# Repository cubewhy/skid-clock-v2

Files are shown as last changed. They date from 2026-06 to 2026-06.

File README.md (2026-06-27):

# Skid Clock v2

> [!IMPORTANT]
>
> 我们假设您拥有3D 打印机或者可以生产外壳。
>
> 如果没有可以用纸盒代替

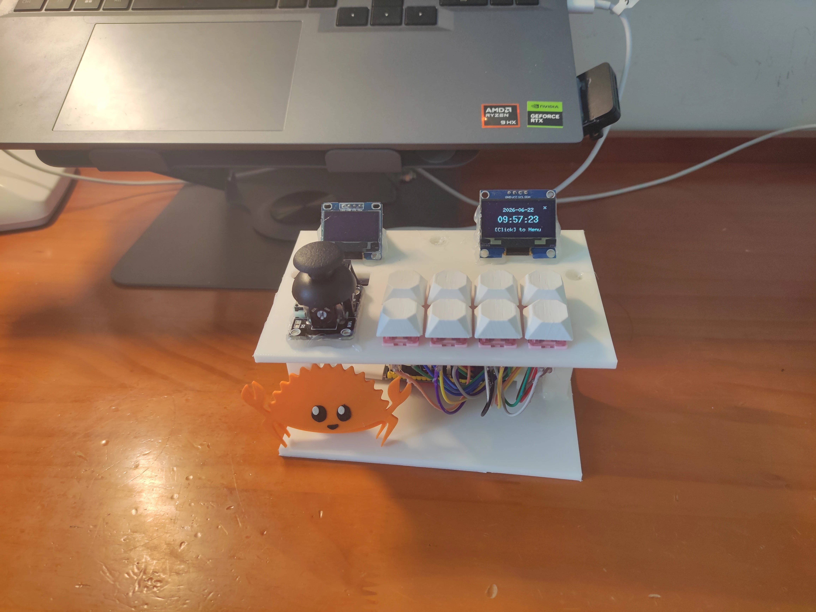
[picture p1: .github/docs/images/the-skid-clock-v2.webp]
the-skid-clock


还在为水课发愁吗? 试试这款桌面时钟, 有一个 ESP32-S3 就可以制作, 轻松跳过水课!

## 功能矩阵

- 时钟
- 停表
- 倒计时
- 番茄钟
- 计算器
- Wi-Fi 连接支持 (支持记忆密码)
- NTP 同步支持
- 小游戏

### 小游戏列表

- 贪吃蛇
- 俄罗斯方块
- 乒乓球
- 谷歌小恐龙
- 堆叠叠罗汉
- 见缝插针
- 打靶
- 跳一跳
- 打地鼠
- 简易版战舰棋
- 坦克动荡
- 2048
- Flappy Bird
- 黄金矿工
- 五子棋
- 打砖块
- 传说之下 (丐版)
- 吃豆人

## 自己组装

### 原材料/工具

| 名称 | 数量 |
| --- | --- |
| ESP32s3 | 1 |
| 机械键盘轴 | 8 |
| 二极管 | 8 |
| 摇杆 | 1 |
| Sh1106 1.3″ 屏幕 | 1 |
| Ssd1306 0.96″ 屏幕 | 1 |
| DS1306 时钟模块 | 1 |
| 面包板 | 1 |
| 杜邦线 | ~45 根 |
| 3D打印机 | 1 (可选) |
| 热熔胶 | 1 |
| 电烙铁 | 1 |
| 镊子 | 1 |

### 制作外壳 (3D打印)

> 如果你要3D 打印键帽: [Printables](https://www.printables.com/model/399607-complete-cherry-mx-stem-keycap-set-optimized-for-3)

- 下载 FreeCAD
- 下载 [工程文件](./models/skid-clock.FCStd) [Printables](https://www.printables.com/model/1765657-skid-clock)
- 导出为 `.3mf` 或者 `.step`
- 用切片软件导出 GCode
- 发送到打印机, 打印!

### 制作外壳 (纸盒子)

- 在顶部开8个 14x14mm 口, 用于放机械键盘按键
- 放入机械键盘按键, 粘贴屏幕和摇杆即可

### 组装

> [!IMPORTANT]
> 先连接电路再粘贴顶板和底板!

- 放置两块屏幕, 用热熔胶粘到外壳的斜坡上
- 将8个轴卡到对应的卡槽中 (不需要热熔胶固定)
- 将杜邦线接到键盘轴上, 并用热熔胶固定 (需要拨开外壳, 使用镊子即可)
- 粘贴摇杆 (没有开槽, 多打一点热熔胶)
- 在顶盖背面粘贴 DS1306 时钟模块
- 将所有线连到 ESP32s3 上 ([引脚信息](#引脚信息))
- 将 ESP32s3 划入底板的卡槽中
- 确认接线无误, 用热熔胶粘贴底板上的三个柱子和顶盖

### 引脚信息

> 你可以在这里找到引脚定义代码 [main.rs](https://github.com/cubewhy/skid-clock-v2/blob/master/src/main.rs)

| GPIO | 说明 |
| ---- | --- |
| 4 | 键盘 row1 |
| 5 | 键盘 row2 |
| 6 | 键盘 col1 |
| 16 | 键盘 col2 |
| 15 | 键盘 col3 |
| 13 | 键盘 col4 |
| 9 | I2C SDA |
| 8 | I2C SCL |
| 10 | DS1306 CLK |
| 11 | DS1306 DAT |
| 12 | DS1306 RST |
| 3 | 摇杆 VRX (X 轴) |
| 7 | 摇杆 VRY (Y 轴) |
| 18 | 摇杆中键 |

#### 搭建矩阵扫描电路

#### I2C 地址

> 你需要使用电烙铁焊接屏幕背后的焊点来切换地址

| 地址 | 说明 |
| ---- | --- |
| 0x3D | 1.3″ OLED 屏幕  |
| 0x3C | 0.96″ OLED 屏幕 |

## License

Licensed under GPL-3.0

You're allowed to use, share and modify

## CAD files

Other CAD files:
models/skid-clock.FCStd

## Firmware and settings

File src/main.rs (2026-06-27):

use std::{
    cell::RefCell,
    sync::{Arc, Mutex},
    thread,
    time::{Duration, Instant},
};

use crate::{
    app_context::{AppContext, UpdateContext},
    apps::App,
    display::{Sh1106Unified, Ssd1306Unified, UnifiedDisplay},
    input::{InputManager, JoystickRotation},
    network_manager::NetworkController,
    pin_config::{
        I2cDisplayPinConfig, JoyPinConfig, KeyboardMatrixConfig, PinConfig, RtcPinConfig,
    },
    rtc::{ds1302::Ds1302, init_timezone, sync_rtc_to_system},
    ui::UiEvents,
};
use embedded_graphics::{draw_target::DrawTarget, pixelcolor::BinaryColor};
use embedded_hal_bus::i2c::RefCellDevice;
use esp_idf_svc::{
    eventloop::EspSystemEventLoop,
    hal::{
        gpio::PinDriver,
        i2c::{I2cConfig, I2cDriver},
        peripherals::Peripherals,
        units::MegaHertz,
    },
    nvs::EspDefaultNvsPartition,
};
use mini_oled::screen::sh1106::Sh1106;
use ssd1306::{I2CDisplayInterface, Ssd1306, mode::DisplayConfig, size::DisplaySize128x64};
use u8g2_fonts::{FontRenderer, fonts};

pub mod app_context;
pub mod apps;
pub mod display;
pub mod input;
pub mod network_manager;
pub mod pin_config;
pub mod rtc;
pub mod secret_manager;
pub mod ui;

fn main() -> anyhow::Result<()> {
    // It is necessary to call this function once. Otherwise, some patches to the runtime
    // implemented by esp-idf-sys might not link properly. See https://github.com/esp-rs/esp-idf-template/issues/71
    esp_idf_svc::sys::link_patches();

    // Bind the log crate to the ESP Logging facilities
    esp_idf_svc::log::EspLogger::initialize_default();

    let peripherals = Peripherals::take().unwrap();
    let sys_loop = EspSystemEventLoop::take()?;
    let nvs = EspDefaultNvsPartition::take()?;
    let pins = peripherals.pins;

    let network_controller = NetworkController::new(peripherals.modem, sys_loop, nvs)?;

    // NOTE: Change the GPIO config if you connected the hardware in different ports
    let pin_config = PinConfig {
        keyboard: KeyboardMatrixConfig {
            rows: [pins.gpio4.degrade_output(), pins.gpio5.degrade_output()],
            cols: [
                pins.gpio6.degrade_input(),
                pins.gpio16.degrade_input(),
                pins.gpio15.degrade_input(),
                pins.gpio13.degrade_input(),
            ],
        },
        i2c_display: I2cDisplayPinConfig {
            sda: pins.gpio9.degrade_input_output(),
            scl: pins.gpio8.degrade_input_output(),
            addr_1_3_in: 0x3D,
            addr_0_96_in: 0x3C,
        },
        rtc: RtcPinConfig {
            clk: pins.gpio10.degrade_output(),
            dat: pins.gpio11.degrade_input_output(),
            rst: pins.gpio12.degrade_output(),
        },
        joy: JoyPinConfig {
            x: pins.gpio3.degrade_input(),
            y: pins.gpio7.degrade_input(),
            sw: pins.gpio18.degrade_input(),
        },
    };

    let mut rtc_driver = {
        let pins = pin_config.rtc;
        let clk_pin = PinDriver::output(pins.clk)?;
        let dat_pin = PinDriver::input_output(pins.dat, esp_idf_svc::hal::gpio::Pull::Floating)?;
        let rst_pin = PinDriver::output(pins.rst)?;

        Ds1302::new(clk_pin, dat_pin, rst_pin)
    };
    rtc_driver.init()?;

    sync_rtc_to_system(&mut rtc_driver)?;

    let mut input_manager = InputManager::build(
        pin_config.keyboard,
        pin_config.joy,
        JoystickRotation::Deg270,
    )?;

    let i2c_cfg = I2cConfig::new().baudrate(MegaHertz::from(1).into());
    let i2c_driver = I2cDriver::new(
        peripherals.i2c0,
        pin_config.i2c_display.sda,
        pin_config.i2c_display.scl,
        &i2c_cfg,
    )?;

    let i2c_bus_shared = RefCell::new(i2c_driver);
    let i2c_dev_for_ssd = RefCellDevice::new(&i2c_bus_shared);
    let i2c_dev_for_sh = RefCellDevice::new(&i2c_bus_shared);

    let ssd_interface = I2CDisplayInterface::new_custom_address(
        i2c_dev_for_ssd,
        pin_config.i2c_display.addr_0_96_in,
    );
    let mut display_0_96 = Ssd1306::new(
        ssd_interface,
        DisplaySize128x64,
        ssd1306::prelude::DisplayRotation::Rotate0,
    )
    .into_buffered_graphics_mode();
    display_0_96
        .init()
        .map_err(|e| anyhow::anyhow!("{:?}", e))?;

    let sh_interface =
        mini_oled::prelude::I2cInterface::new(i2c_dev_for_sh, pin_config.i2c_display.addr_1_3_in);
    let mut display_1_3 = Sh1106::new(sh_interface);
    display_1_3.init().map_err(|e| anyhow::anyhow!("{:?}", e))?;

    let font = FontRenderer::new::<fonts::u8g2_font_6x10_tr>();
    let font_large = FontRenderer::new::<fonts::u8g2_font_10x20_tr>();

    let start_time = Instant::now();

    let mut last_tick = Instant::now();
    let target_frame_time = Duration::from_millis(20); // 50fps

    let mut active_app = App::Clock;

    let shared_events = Arc::new(Mutex::new(Vec::<UiEvents>::new()));

    init_timezone();

    loop {
        input_manager.scan().unwrap();

        let menu_events = input_manager.get_menu_events();

        if !menu_events.is_empty()
            && let Ok(mut events) = shared_events.lock()
        {
            events.push(menu_events);
        }

        let now = Instant::now();
        let elapsed = now.duration_since(last_tick);

        if elapsed >= target_frame_time {
            let frame_events = {
                if let Ok(mut events_guard) = shared_events.lock() {
                    std::mem::take(&mut *events_guard)
                } else {
                    Vec::new()
                }
            };

            if frame_events.is_empty() {
                let mut update_ctx = UpdateContext {
                    menu_events: UiEvents::empty(),
                    rtc: &mut rtc_driver,
                    input_manager: &input_manager,
                    uptime_secs: start_time.elapsed().as_secs(),
                    network: &network_controller,
                };
                if let Some(new_app) = active_app.update(&mut update_ctx) {
                    active_app = new_app;
                }
            } else {
                for events in frame_events {
                    let mut update_ctx = UpdateContext {
                        menu_events: events,
                        rtc: &mut rtc_driver,
                        input_manager: &input_manager,
                        uptime_secs: start_time.elapsed().as_secs(),
                        network: &network_controller,
                    };
                    if let Some(new_app) = active_app.update(&mut update_ctx) {
                        active_app = new_app;
                    }
                }
            }

            let mut app_ctx = AppContext {
                display_0_96: Ssd1306Unified::new(&mut display_0_96),
                display_1_3: Sh1106Unified::new(&mut display_1_3),
                font: &font,
                font_large: &font_large,
                uptime_secs: start_time.elapsed().as_secs(),
                input: &input_manager,
                network: &network_controller,
            };

            app_ctx.display_0_96.clear(BinaryColor::Off).ok();
            app_ctx.display_1_3.clear(BinaryColor::Off).ok();

            active_app.draw(&mut app_ctx)?;

            app_ctx.display_0_96.flush().ok();
            app_ctx.display_1_3.flush().ok();

            last_tick = Instant::now();
        }

        thread::yield_now();
    }
}

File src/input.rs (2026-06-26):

use crate::ui::ctx::UiEvents;
use esp_idf_svc::hal::gpio::{AnyInputPin, Input, Output, PinDriver, Pull};
use std::time::Instant;

const ALL_EVENTS: &[UiEvents] = &[
    UiEvents::UP,
    UiEvents::DOWN,
    UiEvents::LEFT,
    UiEvents::RIGHT,
    UiEvents::CONFIRM,
    UiEvents::KEY_ESC,
    UiEvents::KEY_1,
    UiEvents::KEY_2,
    UiEvents::KEY_3,
    UiEvents::KEY_4,
    UiEvents::KEY_5,
    UiEvents::KEY_6,
    UiEvents::KEY_7,
];

#[derive(Debug, Clone, Copy, PartialEq, Eq)]
pub enum JoystickRotation {
    Deg0,
    Deg90,
    Deg180,
    Deg270,
}

#[derive(Debug, Clone, Copy, Default)]
pub struct JoystickData {
    pub x: f32,
    pub y: f32,
    pub is_pressed: bool,
}

impl JoystickData {
    /// Evaluates stick vectors into UiEvents using hysteresis to prevent border jittering.
    pub fn get_events(&self, prev_events: UiEvents) -> UiEvents {
        let mut events = UiEvents::empty();

        // Hysteresis thresholds to eliminate analog signal noise around boundaries
        let press_thresh: f32 = 0.6;
        let release_thresh: f32 = 0.4;

        // Y-Axis evaluation (UP / DOWN)
        if prev_events.contains(UiEvents::UP) {
            if self.y > release_thresh {
                events.insert(UiEvents::UP);
            }
        } else {
            if self.y > press_thresh {
                events.insert(UiEvents::UP);
            }
        }

        if prev_events.contains(UiEvents::DOWN) {
            if self.y < -release_thresh {
                events.insert(UiEvents::DOWN);
            }
        } else {
            if self.y < -press_thresh {
                events.insert(UiEvents::DOWN);
            }
        }

        // X-Axis evaluation (LEFT / RIGHT) - preserving original mapped polarity
        if prev_events.contains(UiEvents::RIGHT) {
            if self.x < -release_thresh {
                events.insert(UiEvents::RIGHT);
            }
        } else {
            if self.x < -press_thresh {
                events.insert(UiEvents::RIGHT);
            }
        }

        if prev_events.contains(UiEvents::LEFT) {
            if self.x > release_thresh {
                events.insert(UiEvents::LEFT);
            }
        } else {
            if self.x > press_thresh {
                events.insert(UiEvents::LEFT);
            }
        }

        if self.is_pressed {
            events.insert(UiEvents::CONFIRM);
        }

        events
    }
}

#[derive(Debug, Clone, Copy, Default)]
pub struct KeyStates {
    pub esc: bool,
    pub btn_1: bool,
    pub btn_2: bool,
    pub btn_3: bool,
    pub btn_4: bool,
    pub btn_5: bool,
    pub btn_6: bool,
    pub btn_7: bool,
}

impl KeyStates {
    pub fn get_events(&self) -> UiEvents {
        let mut events = UiEvents::empty();

        if self.esc {
            events.insert(UiEvents::KEY_ESC);
        }
        if self.btn_1 {
            events.insert(UiEvents::KEY_1);
        }
        if self.btn_2 {
            events.insert(UiEvents::KEY_2);
        }
        if self.btn_3 {
            events.insert(UiEvents::KEY_3);
        }
        if self.btn_4 {
            events.insert(UiEvents::KEY_4);
        }
        if self.btn_5 {
            events.insert(UiEvents::KEY_5);
        }
        if self.btn_6 {
            events.insert(UiEvents::KEY_6);
        }
        if self.btn_7 {
            events.insert(UiEvents::KEY_7);
        }

        events
    }
}

pub struct InputManager<'a> {
    pub rows: [PinDriver<'a, Output>; 2],
    pub cols: [PinDriver<'a, Input>; 4],

    pub btn_joy_sw: PinDriver<'a, Input>,

    pub joy_x_pin: AnyInputPin<'a>,
    pub joy_y_pin: AnyInputPin<'a>,
    pub joy_rotation: JoystickRotation,

    pub key_states: KeyStates,

    current_events: UiEvents,
    previous_events: UiEvents,
    menu_events: UiEvents,
    released_events: UiEvents,

    last_scan_time: Instant,
    debounce_ms: [u32; 13], // Tracks bounce duration for each UI event
    hold_times_ms: [u32; 13],
    next_trigger_ms: [u32; 13],
}

impl<'a> InputManager<'a> {
    pub const INITIAL_DELAY_MS: u32 = 600;
    pub const REPEAT_RATE_MS: u32 = 50;
    pub const DEBOUNCE_TIME_MS: u32 = 30; // Standard stable window window for switches

    pub fn build(
        keyboard: crate::pin_config::KeyboardMatrixConfig,
        joy: crate::pin_config::JoyPinConfig,
        rotation: JoystickRotation,
    ) -> Result<Self, anyhow::Error> {
        let [row0, row1] = keyboard.rows;
        let mut rows = [PinDriver::output(row0)?, PinDriver::output(row1)?];
        for row in &mut rows {
            row.set_high()?;
        }

        let [col0, col1, col2, col3] = keyboard.cols;
        let cols = [
            PinDriver::input(col0, Pull::Up)?,
            PinDriver::input(col1, Pull::Up)?,
            PinDriver::input(col2, Pull::Up)?,
            PinDriver::input(col3, Pull::Up)?,
        ];

        let btn_joy_sw = PinDriver::input(joy.sw, Pull::Up)?;

        unsafe {
            esp_idf_svc::sys::adc1_config_width(
                esp_idf_svc::sys::adc_bits_width_t_ADC_WIDTH_BIT_12,
            );
            esp_idf_svc::sys::adc1_config_channel_atten(
                esp_idf_svc::sys::adc1_channel_t_ADC1_CHANNEL_2,
                esp_idf_svc::sys::adc_atten_t_ADC_ATTEN_DB_11,
            );
            esp_idf_svc::sys::adc1_config_channel_atten(
                esp_idf_svc::sys::adc1_channel_t_ADC1_CHANNEL_6,
                esp_idf_svc::sys::adc_atten_t_ADC_ATTEN_DB_11,
            );
        }

        Ok(Self {
            rows,
            cols,
            btn_joy_sw,
            joy_x_pin: joy.x,
            joy_y_pin: joy.y,
            joy_rotation: rotation,
            key_states: KeyStates::default(),
            current_events: UiEvents::empty(),
            previous_events: UiEvents::empty(),
            menu_events: UiEvents::empty(),
            released_events: UiEvents::empty(),
            last_scan_time: Instant::now(),
            debounce_ms: [0; 13],
            hold_times_ms: [0; 13],
            next_trigger_ms: [0; 13],
        })
    }

    pub fn scan(&mut self) -> Result<(), anyhow::Error> {
        let now = Instant::now();
        let delta_ms = now.duration_since(self.last_scan_time).as_millis() as u32;
        self.last_scan_time = now;

        self.previous_events = self.current_events;
        self.key_states = KeyStates::default();

        for r in 0..2 {
            self.rows[r].set_low()?;
            unsafe {
                esp_idf_svc::sys::ets_delay_us(5);
            }
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

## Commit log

2026-06-11 fix: change to 20fps
    [main.rs]
2026-06-19 feat: update new 3d model
    [skid-clock.FCStd]
2026-06-19 fix: reverse LEFT and RIGHT
    [input.rs]
2026-06-19 fix: use yield_now instead of sleep 10 ms
    [main.rs]
2026-06-19 fix(dino): back to games menu when press esc
2026-06-19 fix(stack-tower): back to games menu when press esc
2026-06-20 chore(3d): update bottom cover
    [skid-clock.FCStd]
2026-06-22 fix(network): press esc to quit text input
2026-06-22 feat(network): probe network disconnection
2026-06-22 chore(3d-model): change threads raiser to 60 mm
    [skid-clock.FCStd]
2026-06-22 chore(3d-model): remove threads
    [skid-clock.FCStd]
2026-06-26 fix(keyboard): add scan debounce
    [input.rs]
2026-06-27 docs: add printables link
2026-06-27 fix(rtc): sync from system
    [main.rs]
